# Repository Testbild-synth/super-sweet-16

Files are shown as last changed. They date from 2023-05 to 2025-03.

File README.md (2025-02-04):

# "Super Sweet 16" - 16 Step Knob-per-function Sequencer Module for Eurorack
For a while now I've been looking for a through hole diy eurorack sequencer that is as hands-on as the Baby8 but with comfort features 
you would maybe not have with an analog/cmos design. The outcome of my struggle is this module. It is a 16-step sequencer with the following functions:
- variable sequence length up to 16 steps
- Cascading (meaning you can connect multiple to get 32/48/etc steps)
- Builtin quantizer with multiple scales (off, chromatic, major, minor, blues, pentatonic)
- 1-5 octave selectable range
- Holding or pausing notes for each steps
- 2 x Gate and 2x CV out
- splittable (meaning you can have 2 channels for sequence lengths lower than 8)
- Slide pot with CV input for held steps
- Internal clock
- Runs Forwards, backwards and randomly selected steps

## Status - Second revision comfirmed working! code needs a bit of cleanup and I need to upload a youtube explaining the use. Also has a version with the SMD package of the MCP4728 now but that one is not tested!

## Hardware and build
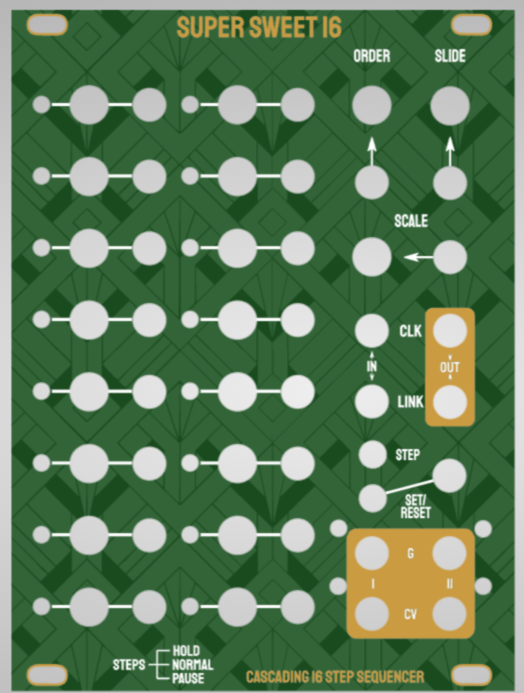
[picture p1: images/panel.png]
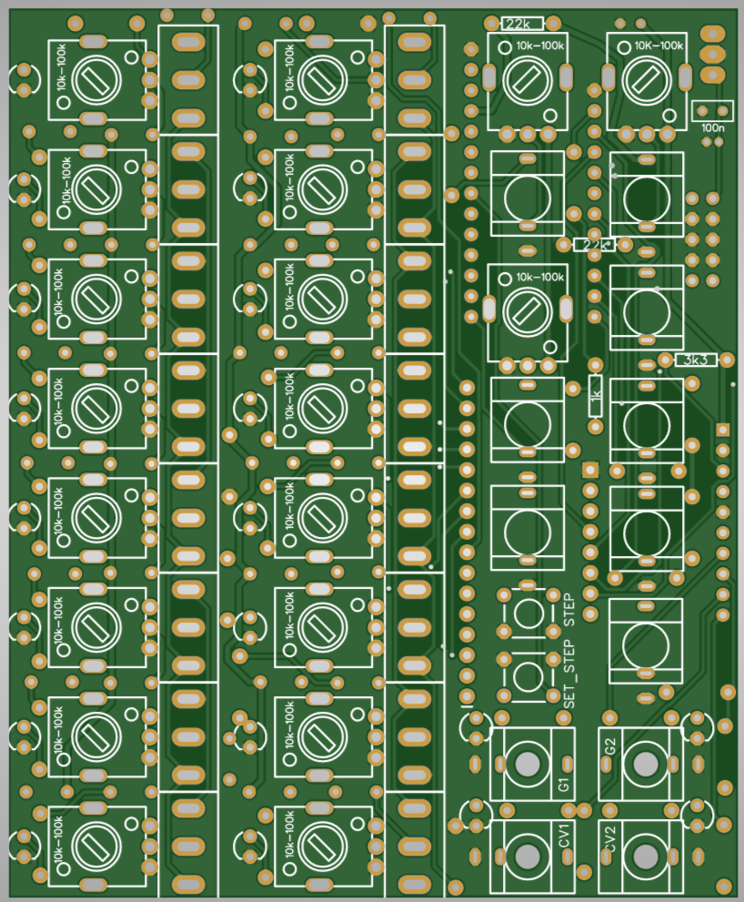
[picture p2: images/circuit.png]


I really wanted this to go on one pcb and while its a bit cramped, it works and I think the build is still doable. 
the panel is 19hp, which is kind of a weird size. If people message me about it I might change it to 20 so that there's a bit more space between knobs but for now I'm fine like this.

you need three ICs: 
- An arduino nano v3, 
- a 4067 mux breakout board (like [this](https://www.ebay.de/itm/273816945682), there's a bunch of these any that has this form factor will do.
- A 4728 dac breakout board (slim form factor, like like [this](https://www.play-zone.ch/de/gy-mcp4728-breakout-quad-i2c-dac-mit-eeprom.html). I wanted through hole only and I had a bunch lying around. If these are hard to source for you, look at the smd_dac versions of the circuitboard (should work but have not been verified yet!).

For the build, I would suggest you go in the following order:
1. diodes
2. headers for arduino and breakout boards
3. resistors (this is important because there are resistors across the input jacks that you should definitely do before the jacks)
4. jacks, pots and the rest
Since the board is a bit cramped you might have to think about the order a bit while building, I didn't have major problems but your mileage might vary.

you can order the pcbs as is with the gerbers provided from any pcb service, I use jlc. Make sure to use leadfree surface finish for the panel as you will be touching silver areas.
**I still have a bunch of PCBs and panels leftover, if you're in the EU and don't wanna order yourself I can sell you a set :)**

## Software

code subfolder contains finished arduino sketch. 

for your arduino to compile and upload properly you need the adafruit_4728 library and the Analog-digital-multiplexers library (https://docs.arduino.cc/libraries/analog-digital-multiplexers/).

To make 16 channels and per-step switches work with an arduino nano and one mux on one pcb, I had to cut a few corners.
The result is that if you have cold solder joints or some contacts are not soldered perfectly you might have a bit of MUX crosstalk (meaning that the frequency at which the mux is switched is so high that there is leftover charge from the last reading).
To check, do the following:
- Set the sequencer to a step length smaller than 8 (see operation)
- plug both CV outputs into something you can read or an oscillator so you will notice changes
- Make sure scale pot is turned all the way counterclockwise (no quantization)
- Turn both CV pots of the active step individually and make sure one does not affect the other (only the output of the pot you turn should change). Turn the SLIDE pot and make sure it doesn't affect the output values.

Mine is fine as is but you can increase the CROSSTALK_DELAY_MS variable in the code. this might decrease crosstalk but increase latency. If you still get problems, redo all solder joints. 
If you still get problems after that tell me and we can talk about changing some resistors, but as I said mine works as is so this might not be needed.

## Operation

Basic operation: 
- Plug in clock into clock input. Pots change value from 0-5V, 
switch changes gate behavior:
  - middle position: "on", gate gets triggered on step change and holds until clock input goes low
  - top position: "hold", gate gets triggered and stays on. You can apply slide to the step value
  - bottom position: "off", no gate gets output
- "Scale" pot applies quantization from left to right: none, chromatic, major, minor, melodic minor, blues, pentatonic, fith and octave, octave.
- "Order" Pot changes sequence order. from left to right: forwards, backwards, random (calculated again each time you switch back and forth)
- "Slide" Pot applies slide (slows down cv change) for all steps where "Hold" is on
- "STEP" button goes to next step
- "RESET STEP" button/CV resets the sequence

Menu:
**Press and hold "reset step"** to get into menu mode. Now you can change the following parameters:
- pressing "STEP" button for a short amount of time turns internal clock on and off. CV leds will blink twice quickly to indicate that the clock is switched on/off.
- holdling "STEP" button for more than a second allows you to change internal clock frequency with the "ORDER" pot. and LED will blink indicating the clock speed.
- turning "SLIDE" pot will change sequence length from 2 to 16. Sequences under 8 automatically enable different values for both channels. LEDs indicate new step length
- turning "SCALE" pot will change maximum output voltage between 1 and 5 volts. this will limit the octaves you want to use but allows more detailed tuning in for step values

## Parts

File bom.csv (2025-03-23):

ID | Name/value | Designator | Quantity | Description | link
1 | 10u | C1 | 1 | Electrolytic capacitor Through hole
2 | 100n | C2,C3 | 2 | Electrolytic capacitor Through hole
3 | BAT43 | D1-D32 | 32 | Schottky diode Through hole
4 | Thonkiconn jack | J1-J3, J5-J13 | 12 | thonkiconn jack. Either spend tons of money or just go to aliexpress | https://de.aliexpress.com/item/1005004890166167.html
7 | MCP4728 | J4 | 1 | MCP4728 module. Link: | https://de.aliexpress.com/item/1005007635284632.html
17 | LED | LED1-LED20 | 20 | Any 3mm through hole led will do.
18 | 10-100k | P1-P16,SCALE,SEQ,SLIDE_AMT | 19 | RV09 potentiometer B10k/B50k/B100k (whichever you prefer). I use these: | https://de.aliexpress.com/item/1005003276146441.html
19 | 16x1_Mux_board_CD74HC4067 | P17 | 1 | Mux breakout board. Like this: | https://de.aliexpress.com/item/1005006761196261.html
20 | POWER | P18 | 1 | Eurorack power header
21 | 10k | R1-R16 | 16
22 | 22k | R17,R18,R19,R26,R27,R28,R29 | 7
23 | 3k3 | R20,R21 | 2
24 | 4.7k | R22,R23,R31,R32 | 4
25 | 1k | R24,R25,R30,R33,R34 | 5
26 | 100K | R35 | 1
27 | 100k | R36 | 1
28 | 1M | R38 | 1
29 | 100R | R40 | 1
30 | SPDT | S1,S2,S3,S4,S5,S6,S7,S8,S9,S10,S11,S12,S13,S14,S15,S16 | 16 | On off on toggle switch MST103-style. Like these | https://de.aliexpress.com/item/1005006881432519.html
31 | ARDUINO_NANO V3 | U1 | 1 | It’s an arduino
32 | STEP, SET_STEP | U2, U3 | 2 | pushbutton 6x6mm. Not sure either what switch and cap to use but these will do I guess | either https://de.aliexpress.com/item/1005005193835619.html or https://www.digikey.de/de/products/detail/cit-relay-and-switch/CT1102S2-8F160/16607856 and these caps https://www.digikey.de/de/products/detail/e-switch/1RWHT/271578
34 | 7805 | U4 | 1 | 7805 voltage regulator

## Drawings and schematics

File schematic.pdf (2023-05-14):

# C9 10 C10 11 C11 12 C12 13 C13 14 C14 15 C15 16

# GND 17 VCC 18 EN 19 S0 20 S1 21 S2 22 S3 23 SIG 24

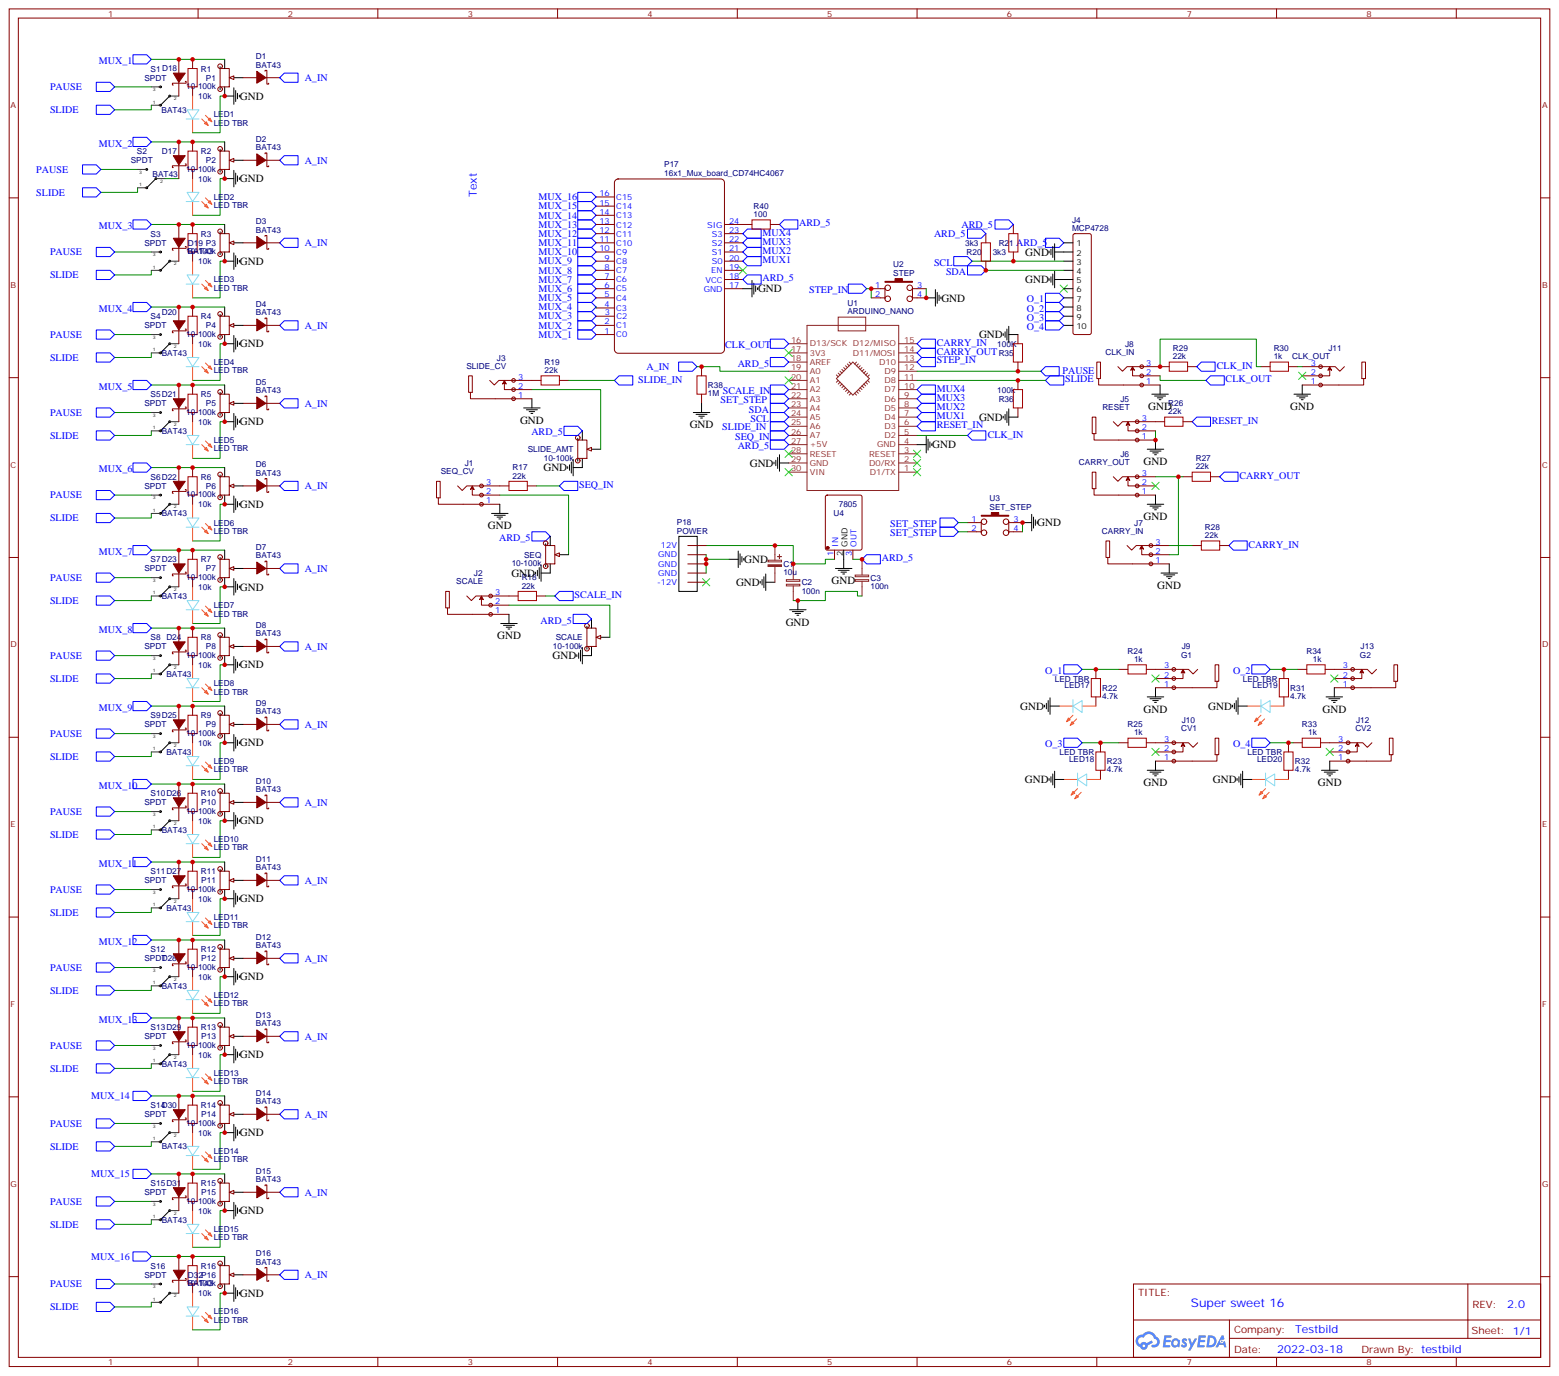
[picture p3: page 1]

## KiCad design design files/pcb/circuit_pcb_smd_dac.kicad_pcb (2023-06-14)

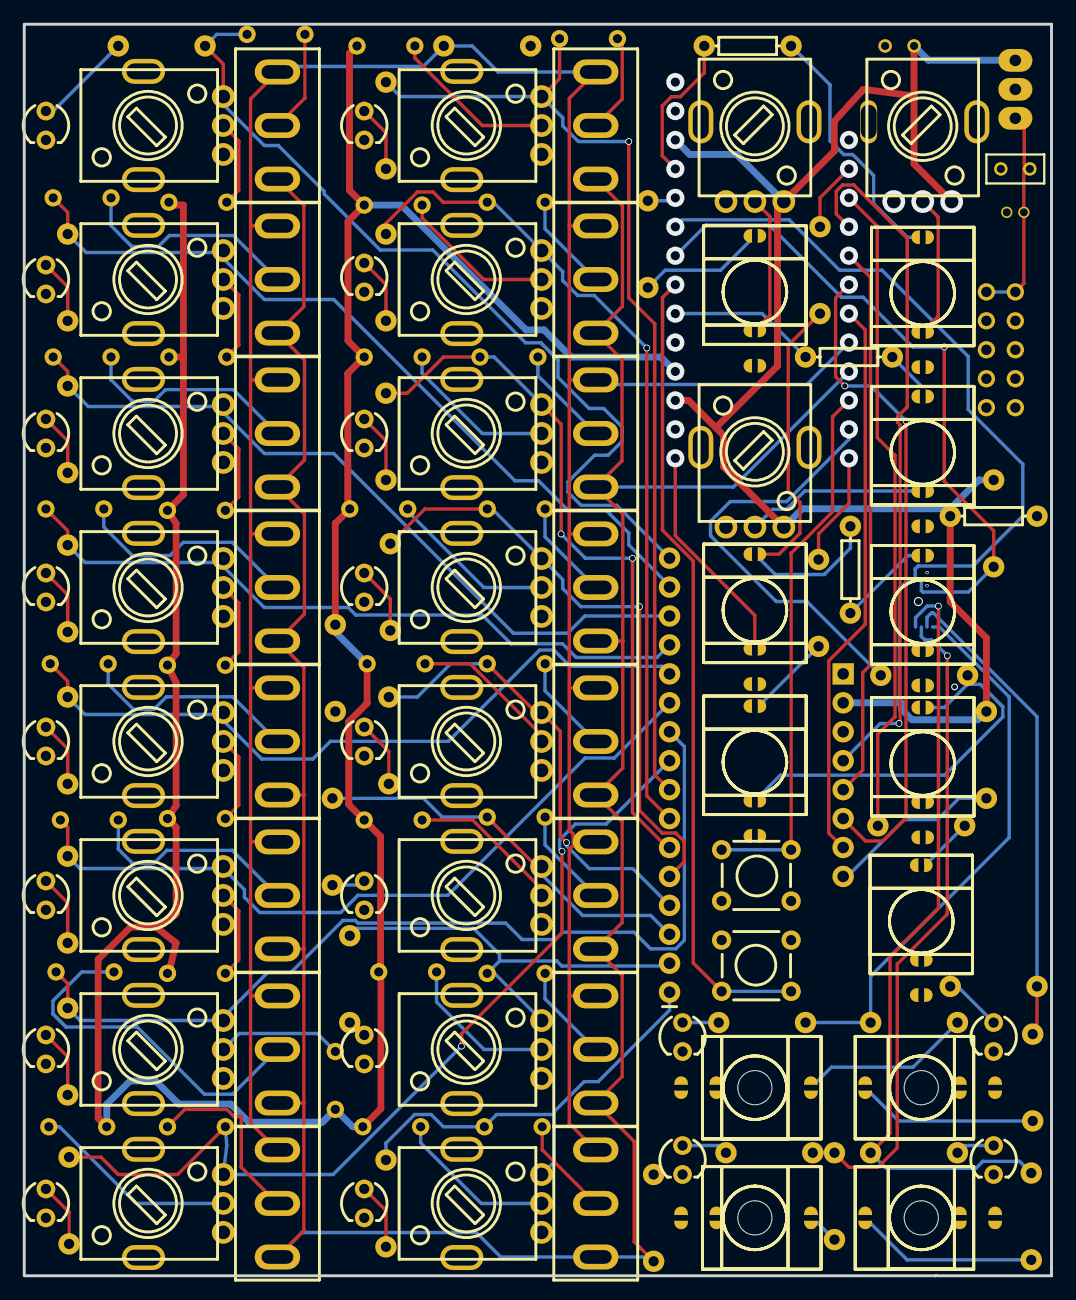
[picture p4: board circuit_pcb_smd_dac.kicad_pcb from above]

Board: 2 copper layers, 90.2 x 109.9 mm, 137 parts (0 on the bottom side), 88 nets.

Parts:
C1: 10u; CAP-D4.0×F1.5
C2, C3: 100n; RAD-0.1
D1, D2, D3, D4, D5, D6, D7, D8, D9, D10, D11, D12, D13, D14, D15, D16, D17, D18, D19, D20, D21, D22, D23, D24, D25, D26, D27, D28, D29, D30, D31, D32: BAT43; DIODE
J9: G1; THONKICONN_1
J10: CV1; THONKICONN_1
J12: CV2; THONKICONN_1
J13: G2; THONKICONN_1
LED1, LED2, LED3, LED4, LED5, LED6, LED7, LED8, LED9, LED10, LED11, LED12, LED13, LED14, LED15, LED16, LED17, LED18, LED19, LED20: LED TBR; LED-3MM/2.54
P1, P2, P3, P4, P5, P6, P7, P8, P9, P10, P11, P12, P13, P14, P15, P16: 10-100k; R09-5KΩ
P17: 16x1_Mux_board_CD74HC4067; CD74HC4067
P18: POWER; EURORACK SHROUDED POWER 10 PIN
R1, R2, R3, R4, R5, R6, R7, R8, R9, R10, R11, R12, R13, R14, R15, R16: 10k; R_AXIAL-0.3
R17, R18, R19, R26, R27, R28, R29: 22k; R_AXIAL-0.3
R20, R21: 3k3; R_AXIAL-0.3
R22, R23, R31, R32: 4.7k; R_AXIAL-0.3
R24, R25, R30, R33, R34: 1k; R_AXIAL-0.3
R35: 100K; R_AXIAL-0.3
R36: 100k; R_AXIAL-0.3
R38: 1M; R_AXIAL-0.3
R40: 100; R_AXIAL-0.3
S1, S2, S3, S4, S5, S6, S7, S8, S9, S10, S11, S12, S13, S14, S15, S16: SPDT; TOGGLE SWITCH SPDT RED 3 PIN ON-OFF-ON 3 SPDT SMALL AC 6A/1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
SCALE: 10-100k; R09-5KΩ
SLIDE_AMT: 10-100k; R09-5KΩ
U2: STEP; PUSHBUTTON
U3: SET_STEP; PUSHBUTTON
U4: 7805
U5: MCP4728; MSOP-10_L3.0-W3.0-P0.50-LS5.0-BL

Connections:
ARD_5: C3.2, P17.18, R20.1, R21.1, R40.1, SCALE.3, SLIDE_AMT.3, U4.3, U5.1
A_IN: D1.2, D2.2, D3.2, D4.2, D5.2, D6.2, D7.2, D8.2, D9.2, D10.2, D11.2, D12.2, D13.2, D14.2, D15.2, D16.2, R38.1
C2_2: C1.1, C2.2, P18.1, U4.1
D2_1: D2.1, P2.2
D3_1: D3.1, P3.2
D4_1: D4.1, P4.2
D5_1: D5.1, P5.2
D6_1: D6.1, P6.2
D7_1: D7.1, P7.2
D8_1: D8.1, P8.2
D9_1: D9.1, P9.2
D10_1: D10.1, P10.2
D11_1: D11.1, P11.2
D12_1: D12.1, P12.2
D13_1: D13.1, P13.2
D14_1: D14.1, P14.2
D15_1: D15.1, P15.2
GND: C1.2, C2.1, C3.1, J9.1, J10.1, J12.1, J13.1, LED1.2, LED2.2, LED3.2, LED4.2, LED5.2, LED6.2, LED7.2, LED8.2, LED9.2, LED10.2, LED11.2, LED12.2, LED13.2, LED14.2, LED15.2, LED16.2, LED17.2, LED18.2, LED19.2, LED20.2, P1.1, P2.1, P3.1, P4.1, P5.1, P6.1, P7.1, P8.1, P9.1, P10.1, P11.1, P12.1, P13.1, P14.1, P15.1, P16.1, P17.17, P18.2, P18.3, P18.4, R35.1, R36.2, R38.2, SCALE.1, SLIDE_AMT.1, U2.3, U2.4, U3.3, U3.4, U4.2, U5.4, U5.10
J8_3: R29.2, R30.2
J10_3: J10.3, R25.2
J12_3: J12.3, R33.2
J13_3: J13.3, R34.2
LED2_1: LED2.1, R2.2
LED3_1: LED3.1, R3.2
LED4_1: LED4.1, R4.2
LED5_1: LED5.1, R5.2
LED6_1: LED6.1, R6.2
LED7_1: LED7.1, R7.2
LED8_1: LED8.1, R8.2
LED9_1: LED9.1, R9.2
LED10_1: LED10.1, R10.2
LED11_1: LED11.1, R11.2
LED12_1: LED12.1, R12.2
LED13_1: LED13.1, R13.2
LED14_1: LED14.1, R14.2
LED15_1: LED15.1, R15.2
MUX_1: D18.1, P1.3, P17.1, R1.1
MUX_2: D17.1, P2.3, P17.2, R2.1
MUX_3: D19.1, P3.3, P17.3, R3.1
MUX_4: D20.1, P4.3, P17.4, R4.1
MUX_5: D21.1, P5.3, P17.5, R5.1
MUX_6: D22.1, P6.3, P17.6, R6.1
MUX_7: D23.1, P7.3, P17.7, R7.1
MUX_8: D24.1, P8.3, P17.8, R8.1
MUX_9: D25.1, P9.3, P17.9, R9.1
MUX_10: D26.1, P10.3, P17.10, R10.1
MUX_11: D27.1, P11.3, P17.11, R11.1
MUX_12: D28.1, P12.3, P17.12, R12.1
MUX_13: D29.1, P13.3, P17.13, R13.1
MUX_14: D30.1, P14.3, P17.14, R14.1
MUX_15: D31.1, P15.3, P17.15, R15.1
MUX_16: D32.1, P16.3, P17.16, R16.1
O_1: R22.1, R24.1, U5.6
O_2: R31.1, R34.1, U5.7
O_3: R23.1, R25.1, U5.8
O_4: R32.1, R33.1, U5.9
P1_2: D1.1, P1.2
P16_2: D16.1, P16.2
P17_24: P17.24, R40.2
PAUSE: R35.2, S1.3, S2.3, S3.3, S4.3, S5.3, S6.3, S7.3, S8.3, S9.3, S10.3, S11.3, S12.3, S13.3, S14.3, S15.3, S16.3
R1_2: LED1.1, R1.2
R16_2: LED16.1, R16.2
R22_2: LED17.1, R22.2
R23_2: LED18.1, R23.2
R24_2: J9.3, R24.2
R31_2: LED19.1, R31.2
R32_2: LED20.1, R32.2
S1_2: D18.2, S1.2
S2_2: D17.2, S2.2
S3_2: D19.2, S3.2
S4_2: D20.2, S4.2
S5_2: D21.2, S5.2
S6_2: D22.2, S6.2
S7_2: D23.2, S7.2
S8_2: D24.2, S8.2
S9_2: D25.2, S9.2
S10_2: D26.2, S10.2
S11_2: D27.2, S11.2
S12_2: D28.2, S12.2
S13_2: D29.2, S13.2
S14_2: D30.2, S14.2
S15_2: D31.2, S15.2
S16_2: D32.2, S16.2
SCL: R21.2, U5.2
SDA: R20.2, U5.3
SET_STEP: U3.1, U3.2
SLIDE: R36.1, S1.1, S2.1, S3.1, S4.1, S5.1, S6.1, S7.1, S8.1, S9.1, S10.1, S11.1, S12.1, S13.1, S14.1, S15.1, S16.1
STEP_IN: U2.1, U2.2

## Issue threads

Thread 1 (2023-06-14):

MCP4728 breakout is difficult to source!

KeLaiFu, 2023-06-14:
You mentioned in the info that you could put the MCP4728 directly onto the board. Is this still a possibility? I've used those boards in a midi module before and they were very difficult to get hold of (a few years ago) .

I'm thinking of reformatting your 16 step sequencer to an MFOS style radial one, it's something I've always liked the look of, but the little MCP4728 boards will be a hurdle.

Nice work BTW, looks like an awesome sequencer!

Testbild-synth, 2023-06-14:
sure, i'll try to upload a version that uses the chip instead of the breakout board within this week. You'll have to test it yourself though I'm not gonna order/build another one I already have two

Testbild-synth, 2023-06-14:
Actually I hacked something together over lunch break. I am not sure but looking at the datasheet, the MSSOP version of the same dac should not need any outside components so fingers crossed that this will work with the exact same code.  [look at the recent commit](https://github.com/Testbild-synth/super-sweet-16/commit/a468284f42ba96e61710e28b261b8d9ac19b1965).
A MFOS style ring version would be great but might be a bit crowded to get 16 pots and 16 switches in that format.

KeLaiFu, 2023-06-14:
> Actually I hacked something together over lunch break. I am not sure but looking at the datasheet, the MSSOP version of the same dac should not need any outside components so fingers crossed that this will work with the exact same code. [look at the recent commit](https://github.com/Testbild-synth/super-sweet-16/commit/a468284f42ba96e61710e28b261b8d9ac19b1965). A MFOS style ring version would be great but might be a bit crowded to get 16 pots and 16 switches in that format.

Thanks! I'll take a look. I just mentioned this to a friend of mine and he said he's working on cloning the little 4728 PCB, so I may wait on that.
16 pots is a bit of a squeeze for sure, but I plan to move the switches to a little bank on the right of the ring, which should help.

Closed 2025-02-19.

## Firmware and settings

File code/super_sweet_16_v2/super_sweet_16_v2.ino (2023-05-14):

#include "Mux.h"
#include <CD74HC4067.h>
#include <Adafruit_MCP4728.h>
#include <Wire.h>


Adafruit_MCP4728 mcp;

#define CLK_IN 2
#define RESET_IN 3

#define MUX1 4
#define MUX2 5
#define MUX3 6
#define MUX4 7
#define PAUSE_SW 8
#define HOLD_NOTE_SW 9
#define STEP_BUTTON 10
#define CARRY_OUT 11
#define CARRY_IN 12

#define CLOCK_OUT 13
#define ACTIVE_STEP_POT A0

#define SCALE_POT A2
#define RESET_SET_STEP_BUTTON A3
#define SLIDE_POT A7
#define ORDER_POT A6

//this is how long the mux needs to settle to prevent crosstalk with my circuit.
//if you still get crosstalk, set it higher
#define MUX_DELAY_CROSSTALK_US 300
CD74HC4067 my_mux(MUX1, MUX2, MUX3, MUX4);

int step_count = 0;
int max_step = 15;
unsigned long last_step_time = 0;
int debounce_timer = 30;

int clock_ms = 600;
bool internal_clock_enable = false;

bool gate = false;
int gate1_out, gate2_out = 0;

int value = 0;
uint8_t scale_val = 0;
uint8_t seq_val = 0;
uint8_t note = 0;
uint16_t out_values[61] = {0, 68, 136, 205, 273, 341, 410, 478, 546, 614, 682, 751, 819, 887, 956, 1024, 1092, 1160, 1228, 1297, 1365, 1433, 1502, 1570, 1638, 1706, 1774, 1843, 1911, 1979, 2048, 2116, 2184, 2252, 2320, 2389, 2457, 2525, 2594, 2662, 2730, 2798, 2866, 2935, 3003, 3071, 3140, 3208, 3276, 3344, 3412, 3481, 3549, 3617, 3686, 3754, 3822, 3890, 3958, 4027, 4095};
uint8_t notes[1024] = {0, 0, 0, 0, 0, 0, 0, 0, 0, 0, 0, 0, 0, 0, 0, 0, 0, 0, 1, 1, 1, 1, 1, 1, 1, 1, 1, 1, 1, 1, 1, 1, 1, 1, 1, 2, 2, 2, 2, 2, 2, 2, 2, 2, 2, 2, 2, 2, 2, 2, 2, 2, 3, 3, 3, 3, 3, 3, 3, 3, 3, 3, 3, 3, 3, 3, 3, 3, 3, 4, 4, 4, 4, 4, 4, 4, 4, 4, 4, 4, 4, 4, 4, 4, 4, 4, 5, 5, 5, 5, 5, 5, 5, 5, 5, 5, 5, 5, 5, 5, 5, 5, 5, 6, 6, 6, 6, 6, 6, 6, 6, 6, 6, 6, 6, 6, 6, 6, 6, 6, 7, 7, 7, 7, 7, 7, 7, 7, 7, 7, 7, 7, 7, 7, 7, 7, 7, 8, 8, 8, 8, 8, 8, 8, 8, 8, 8, 8, 8, 8, 8, 8, 8, 8, 9, 9, 9, 9, 9, 9, 9, 9, 9, 9, 9, 9, 9, 9, 9, 9, 9, 10, 10, 10, 10, 10, 10, 10, 10, 10, 10, 10, 10, 10, 10, 10, 10, 10, 11, 11, 11, 11, 11, 11, 11, 11, 11, 11, 11, 11, 11, 11, 11, 11, 11, 12, 12, 12, 12, 12, 12, 12, 12, 12, 12, 12, 12, 12, 12, 12, 12, 12, 13, 13, 13, 13, 13, 13, 13, 13, 13, 13, 13, 13, 13, 13, 13, 13, 13, 14, 14, 14, 14, 14, 14, 14, 14, 14, 14, 14, 14, 14, 14, 14, 14, 14, 15, 15, 15, 15, 15, 15, 15, 15, 15, 15, 15, 15, 15, 15, 15, 15, 15, 15, 16, 16, 16, 16, 16, 16, 16, 16, 16, 16, 16, 16, 16, 16, 16, 16, 16, 17, 17, 17, 17, 17, 17, 17, 17, 17, 17, 17, 17, 17, 17, 17, 17, 17, 18, 18, 18, 18, 18, 18, 18, 18, 18, 18, 18, 18, 18, 18, 18, 18, 18, 19, 19, 19, 19, 19, 19, 19, 19, 19, 19, 19, 19, 19, 19, 19, 19, 19, 20, 20, 20, 20, 20, 20, 20, 20, 20, 20, 20, 20, 20, 20, 20, 20, 20, 21, 21, 21, 21, 21, 21, 21, 21, 21, 21, 21, 21, 21, 21, 21, 21, 21, 22, 22, 22, 22, 22, 22, 22, 22, 22, 22, 22, 22, 22, 22, 22, 22, 22, 23, 23, 23, 23, 23, 23, 23, 23, 23, 23, 23, 23, 23, 23, 23, 23, 23, 24, 24, 24, 24, 24, 24, 24, 24, 24, 24, 24, 24, 24, 24, 24, 24, 24, 25, 25, 25, 25, 25, 25, 25, 25, 25, 25, 25, 25, 25, 25, 25, 25, 25, 26, 26, 26, 26, 26, 26, 26, 26, 26, 26, 26, 26, 26, 26, 26, 26, 26, 27, 27, 27, 27, 27, 27, 27, 27, 27, 27, 27, 27, 27, 27, 27, 27, 27, 28, 28, 28, 28, 28, 28, 28, 28, 28, 28, 28, 28, 28, 28, 28, 28, 28, 29, 29, 29, 29, 29, 29, 29, 29, 29, 29, 29, 29, 29, 29, 29, 29, 29, 30, 30, 30, 30, 30, 30, 30, 30, 30, 30, 30, 30, 30, 30, 30, 30, 30, 30, 31, 31, 31, 31, 31, 31, 31, 31, 31, 31, 31, 31, 31, 31, 31, 31, 31, 32, 32, 32, 32, 32, 32, 32, 32, 32, 32, 32, 32, 32, 32, 32, 32, 32, 33, 33, 33, 33, 33, 33, 33, 33, 33, 33, 33, 33, 33, 33, 33, 33, 33, 34, 34, 34, 34, 34, 34, 34, 34, 34, 34, 34, 34, 34, 34, 34, 34, 34, 35, 35, 35, 35, 35, 35, 35, 35, 35, 35, 35, 35, 35, 35, 35, 35, 35, 36, 36, 36, 36, 36, 36, 36, 36, 36, 36, 36, 36, 36, 36, 36, 36, 36, 37, 37, 37, 37, 37, 37, 37, 37, 37, 37, 37, 37, 37, 37, 37, 37, 37, 38, 38, 38, 38, 38, 38, 38, 38, 38, 38, 38, 38, 38, 38, 38, 38, 38, 39, 39, 39, 39, 39, 39, 39, 39, 39, 39, 39, 39, 39, 39, 39, 39, 39, 40, 40, 40, 40, 40, 40, 40, 40, 40, 40, 40, 40, 40, 40, 40, 40, 40, 41, 41, 41, 41, 41, 41, 41, 41, 41, 41, 41, 41, 41, 41, 41, 41, 41, 42, 42, 42, 42, 42, 42, 42, 42, 42, 42, 42, 42, 42, 42, 42, 42, 42, 43, 43, 43, 43, 43, 43, 43, 43, 43, 43, 43, 43, 43, 43, 43, 43, 43, 44, 44, 44, 44, 44, 44, 44, 44, 44, 44, 44, 44, 44, 44, 44, 44, 44, 45, 45, 45, 45, 45, 45, 45, 45, 45, 45, 45, 45, 45, 45, 45, 45, 45, 45, 46, 46, 46, 46, 46, 46, 46, 46, 46, 46, 46, 46, 46, 46, 46, 46, 46, 47, 47, 47, 47, 47, 47, 47, 47, 47, 47, 47, 47, 47, 47, 47, 47, 47, 48, 48, 48, 48, 48, 48, 48, 48, 48, 48, 48, 48, 48, 48, 48, 48, 48, 49, 49, 49, 49, 49, 49, 49, 49, 49, 49, 49, 49, 49, 49, 49, 49, 49, 50, 50, 50, 50, 50, 50, 50, 50, 50, 50, 50, 50, 50, 50, 50, 50, 50, 51, 51, 51, 51, 51, 51, 51, 51, 51, 51, 51, 51, 51, 51, 51, 51, 51, 52, 52, 52, 52, 52, 52, 52, 52, 52, 52, 52, 52, 52, 52, 52, 52, 52, 53, 53, 53, 53, 53, 53, 53, 53, 53, 53, 53, 53, 53, 53, 53, 53, 53, 54, 54, 54, 54, 54, 54, 54, 54, 54, 54, 54, 54, 54, 54, 54, 54, 54, 55, 55, 55, 55, 55, 55, 55, 55, 55, 55, 55, 55, 55, 55, 55, 55, 55, 56, 56, 56, 56, 56, 56, 56, 56, 56, 56, 56, 56, 56, 56, 56, 56, 56, 57, 57, 57, 57, 57, 57, 57, 57, 57, 57, 57, 57, 57, 57, 57, 57, 57, 58, 58, 58, 58, 58, 58, 58, 58, 58, 58, 58, 58, 58, 58, 58, 58, 58, 59, 59, 59, 59, 59, 59, 59, 59, 59, 59, 59, 59, 59, 59, 59, 60, 60};
uint8_t num_octaves = 5;
float aread_offset = 1.06;
float cv1_out, cv2_out, cv1_out_temp, cv2_out_temp = 0;

float slide_alpha = 0.0;
bool ch1_hold, ch2_hold, ch1_pause, ch2_pause = false;

//updated via check_seq_order()
uint8_t step_order[16] = {0, 1, 2, 3, 4, 5, 6, 7, 8, 9, 10, 11, 12, 13, 14, 15};

uint8_t max_step_pot_value = 0;
uint8_t scales[8][12] = {{0, 1, 2, 3, 4, 5, 6, 7, 8, 9, 10, 11}, //chromatic
  {0, 0, 2, 2, 4, 5, 5, 7, 7, 9, 9 , 11}, //major
  {0, 0, 2, 3, 3, 5, 5, 7, 8, 8, 10, 10}, //minor
  {0, 0, 2, 3, 3, 5, 5, 7, 7, 9, 9, 11}, //melodic minor
  {0, 0, 0, 3, 3, 5, 6, 7, 7, 9, 9, 11}, //blues
  {0, 0, 0, 3, 3, 5, 5, 7, 7, 7, 10, 10}, // pentatonic
  {0, 0, 0, 0, 0, 0, 0, 7, 7, 7, 12, 12}, //oct and quint
  {0, 0, 0, 0, 0, 0, 0, 12, 12, 12, 12, 12} // oct
}; //oct

void update_dac(int valueA, int valueB, int valueC, int valueD) {
  mcp.setChannelValue(MCP4728_CHANNEL_A, valueA);
  mcp.setChannelValue(MCP4728_CHANNEL_B, valueB);
  mcp.setChannelValue(MCP4728_CHANNEL_C, valueC);
  mcp.setChannelValue(MCP4728_CHANNEL_D, valueD);
}

void setup() {
  pinMode(ACTIVE_STEP_POT, INPUT);
  pinMode(MUX1, OUTPUT);
  pinMode(MUX2, OUTPUT);
  pinMode(MUX3, OUTPUT);
  pinMode(MUX4, OUTPUT);

  pinMode(RESET_SET_STEP_BUTTON, INPUT_PULLUP);
  digitalWrite(RESET_SET_STEP_BUTTON, HIGH);
  pinMode(SCALE_POT, INPUT);
  pinMode(SLIDE_POT, INPUT);
  pinMode(ORDER_POT, INPUT);
  pinMode(STEP_BUTTON, INPUT_PULLUP);
  digitalWrite(STEP_BUTTON, HIGH);
  pinMode(CARRY_OUT, OUTPUT);
  pinMode(CARRY_IN, INPUT);
  
  pinMode(RESET_IN, INPUT);
  pinMode(HOLD_NOTE_SW, INPUT);
  pinMode(PAUSE_SW, INPUT);
  pinMode(CLOCK_OUT, OUTPUT);
  attachInterrupt(digitalPinToInterrupt(CLK_IN), clk_step_update, CHANGE);
  attachInterrupt(digitalPinToInterrupt(RESET_IN), reset_counter, RISING);
  analogReference(EXTERNAL);

  while (true) {
    if (mcp.begin()) {
      break;
    }
    delay(100);
  }
  for (int i = 0; i < 16; i++) {
    my_mux.channel(i);
    update_dac(i * 255, i * 255, i * 255, i * 255);
    delay(100);
  }
  for (int i = 15; i >= 0 ; i--) {
    my_mux.channel(i);
    update_dac(i * 255, i * 255, i * 255, i * 255);
    delay(100);
  }
}

void reset_counter() {
  step_count = 0;
}

void update_channel_values(int& gate_out, float& temp_cv_out, float& cv_out) {
  delayMicroseconds(10);
  if ((gate || digitalRead(HOLD_NOTE_SW)) && !digitalRead(PAUSE_SW)) {
    gate_out = 4095;
  }
  else {
    gate_out = 0;
  }
  (void)analogRead(ACTIVE_STEP_POT);
  delayMicroseconds(100);
  if (scale_val == 0) {
    temp_cv_out = aread_offset * float(analogRead(ACTIVE_STEP_POT)) * 4 * float(num_octaves) / 5.0;

  }
  else {
    note = int(notes[constrain(int(aread_offset * float(analogRead(ACTIVE_STEP_POT))), 0, 1023)] * float(num_octaves) / 5.0);
    note = note - note % 12  + scales[scale_val][note % 12];
    temp_cv_out = out_values[note];
  }
  if (digitalRead(HOLD_NOTE_SW)) {
    cv_out = constrain(temp_cv_out * (1 - slide_alpha) + cv_out * (slide_alpha), 0, 4095.0);
  }
  else {
    cv_out = constrain(temp_cv_out, 0, 4095.0);
  }
}


void update_split() {
  // update channel 1
  slide_alpha = float(analogRead(SLIDE_POT) / 1200.0);
  my_mux.channel(step_order[step_count]);
  delayMicroseconds(MUX_DELAY_CROSSTALK_US);
  update_channel_values(gate1_out, cv1_out_temp, cv1_out);

  my_mux.channel(step_order[step_count] + 8);
  delayMicroseconds(MUX_DELAY_CROSSTALK_US);
  update_channel_values(gate2_out, cv2_out_temp, cv2_out);
  update_dac(gate1_out, gate2_out, int(cv1_out), int(cv2_out));
}


void update_dual() {
  slide_alpha = float(analogRead(SLIDE_POT) / 1024.0);
  my_mux.channel(step_order[step_count]);
  delayMicroseconds(MUX_DELAY_CROSSTALK_US);
  update_channel_values(gate1_out, cv1_out_temp, cv1_out);
  update_dac(gate1_out, gate1_out, int(cv1_out), int(cv1_out));
}



void update_gate_and_cv() {
  scale_val = round(analogRead(SCALE_POT) / 128);

  if (max_step < 8) {
    update_split();
  }
  else {
    update_dual();
  }
}


void button_step_update(bool button_value){
  if (((millis() - last_step_time) < debounce_timer)){
    return;
  }
  last_step_time = millis();
  if(!button_value){
    if(step_count < max_step){
      digitalWrite(CARRY_OUT, LOW);
      step_count += 1;
      if(step_count == max_step){
        digitalWrite(CARRY_OUT, HIGH);
        delayMicroseconds(1);
    }
    }
    else if (digitalRead(CARRY_IN)){
      step_count = 0;
      digitalWrite(CARRY_OUT, LOW);
    }
   }
   gate = !button_value;
}

void clk_step_update(){
  if (((millis() - last_step_time) < debounce_timer)){
    return;
  }
  last_step_time = millis();
  if(digitalRead(CLK_IN)){
      if(step_count < max_step){
      digitalWrite(CARRY_OUT, LOW);
      step_count += 1;
      if(step_count == max_step){
        digitalWrite(CARRY_OUT, HIGH);
        delayMicroseconds(1);
      }
      }
      else if (digitalRead(CARRY_IN)){
      step_count = 0;
      digitalWrite(CARRY_OUT, LOW);
    }
    gate = true;
  }
  else{
    gate = false;
  }
}

void check_seq_order(bool recalculate) {
  if ((seq_val != analogRead(ORDER_POT) / 256) || recalculate) {
    seq_val =  analogRead(ORDER_POT) / 256;

    //normal
    if (seq_val == 0) {
      if (max_step < 8) {
        for (int i = 0; i < 8; i++) {
          step_order[i] = i;
          step_order[i + 8] = i;
        }
      }
      else {
        for (int i = 0; i < 16; i++) {
          step_order[i] = i;
        }
      }
    }
    // backwards
    else if (seq_val == 1) {
      if (max_step < 8) {
        for (int i = max_step; i >= 0; i--) {
          step_order[max_step - i] = i;
          step_order[max_step - i + 8] = i;
        }
      }
      else {
        for (int i = max_step; i >= 0; i--) {
          step_order[max_step - i] = i;
        }
      }
    }
    // random
    else if (seq_val == 2) {
      for (int i = max_step; i > 0; i--)
      {
        long j = random(0, max_step);
        swap(&step_order[i], &step_order[j]);
      }
      if (max_step < 8) {
        for (int i = max_step; i >= 0; i--) {
          step_order[i + 8] = step_order[i];
        }
      }
    }
  }
}

void swap (uint8_t *a, uint8_t *b)
{
  int temp = *a;
  *a = *b;
  *b = temp;
}

//set the step count, disable interrupts
void reset_set_step() {
  int start_max_steps_setting = floor(analogRead(SLIDE_POT) / 64);
  int start_num_octaves_setting = constrain(round(analogRead(SCALE_POT) / 190), 1, 5);
  digitalWrite(CLOCK_OUT, LOW);
  int settings_timer = millis();
  while (!digitalRead(RESET_SET_STEP_BUTTON)) {
    if ((millis() - settings_timer) > 500) {
      
      // turn on internal clock and allow settings while both buttons are pressed
      if(!digitalRead(STEP_BUTTON)){
        internal_clock_enable = !internal_clock_enable;
        mcp.setChannelValue(MCP4728_CHANNEL_C, 4000);
        mcp.setChannelValue(MCP4728_CHANNEL_D, 4000);
        delay(200);
        mcp.setChannelValue(MCP4728_CHANNEL_C, 0);
        mcp.setChannelValue(MCP4728_CHANNEL_D, 0);
        delay(200);
        mcp.setChannelValue(MCP4728_CHANNEL_C, 4000);
        mcp.setChannelValue(MCP4728_CHANNEL_D, 4000);
        delay(200);
        mcp.setChannelValue(MCP4728_CHANNEL_C, 0);
        mcp.setChannelValue(MCP4728_CHANNEL_D, 0);
        delay(200);
        int start_clock_setting = analogRead(ORDER_POT)/128;
        while(!digitalRead(STEP_BUTTON) && internal_clock_enable){
          clock_out(false, true);
          if (start_clock_setting != analogRead(ORDER_POT)/128){
            clock_ms = constrain(3100-analogRead(ORDER_POT)*3, 50, 3000); 
          }
        }
      }
      // press both buttons - switch between detailed and full mode
      if (constrain(round(analogRead(SCALE_POT) / 190), 1, 5) != start_num_octaves_setting) {
        num_octaves = constrain(round(analogRead(SCALE_POT) / 190), 1, 5);
        update_dac(800 * num_octaves, 800 * num_octaves, 800 * num_octaves, 800 * num_octaves);
        delay(1);
      }
      if (floor(analogRead(SLIDE_POT) / 64) != start_max_steps_setting) {
        max_step = floor(analogRead(SLIDE_POT) / 64);
        if (max_step < 8) {
          for (int i = 0; i <= max_step; i++) {
            my_mux.channel(i);
            delay(1);
            my_mux.channel(i + 8);
            delay(1);
          }
        }
        else {
          update_dac(4095, 0, max_step * 255, max_step * 255);
          for (int i = 0; i <= max_step; i++) {
            my_mux.channel(i);
            delay(1);
          }
        }
      }
    }
  }
  mcp.setChannelValue(MCP4728_CHANNEL_A, 0);
  mcp.setChannelValue(MCP4728_CHANNEL_B, 0);
  mcp.setChannelValue(MCP4728_CHANNEL_C, 0);
  mcp.setChannelValue(MCP4728_CHANNEL_D, 0);
  step_count = 0;
}

void clock_out(bool pin, bool dac){
  if(internal_clock_enable){
    if(pin){
      digitalWrite(CLOCK_OUT, ((millis() % clock_ms) < int(clock_ms/2)));
    }
    if(dac){
       mcp.setChannelValue(MCP4728_CHANNEL_A, ((millis() % clock_ms) < int(clock_ms/2))*4000);
    }
  }
}

bool button_val = false;

void loop() {
  clock_out(true, false);
  if (!digitalRead(RESET_SET_STEP_BUTTON)) {
    reset_set_step();
  }
  if (digitalRead(STEP_BUTTON) != button_val){
    button_val = digitalRead(STEP_BUTTON);
    button_step_update(button_val);
  }
  check_seq_order(false);
  update_gate_and_cv();
}

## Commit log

2023-05-14 file upload p1
    [circuit_pcb.kicad_pcb, super_sweet_16.kicad_pcb]
2023-05-14 code and schematic upload
    [bom_not_cleaned_yet.csv]
2023-05-15 upload gerber images
2023-06-14 Added first wip version for smd dac - not tested!
    [circuit_pcb_smd_dac.kicad_pcb]
2025-02-04 clean up bom
    [bom.csv, bom_not_cleaned_yet.csv]
2025-02-04 took need to update bom out or readme
